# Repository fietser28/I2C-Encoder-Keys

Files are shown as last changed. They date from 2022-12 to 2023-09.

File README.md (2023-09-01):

<!--
  SPDX-FileCopyrightText: 2023 Jan Nieuwstad <jan.sources@nieuwstad.net>
  SPDX-License-Identifier: CERN-OHL-W-2.0
-->



# Introduction

This is simple design to connect a rotary encoder with pushbutton and 4 switches to an MCU using I2C. The design uses the common MCP23008 chip. The BOM is kept simple with as many common parts as possible. The encoder and switches have a small RC network in place for basic debouncing (you still need to handle this also in software).

The board breaks out 3V3 power input, GND, SCL, SDA, Interrupt and !Reset.

The board provides pull up resistors for SCL, SDA and the !RESET pin. For each of them there also is a jumper to disable them.

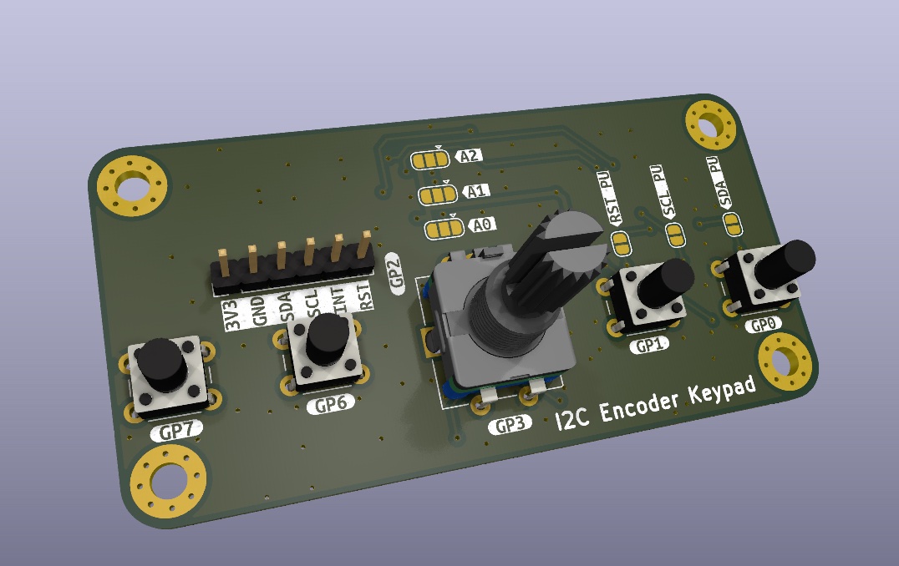
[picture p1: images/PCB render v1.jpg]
alt Raytraced front of PCB with components


NOTE: The rendering above has an encoder with round shaft, the knob is for an encoder with a D shaped shaft.

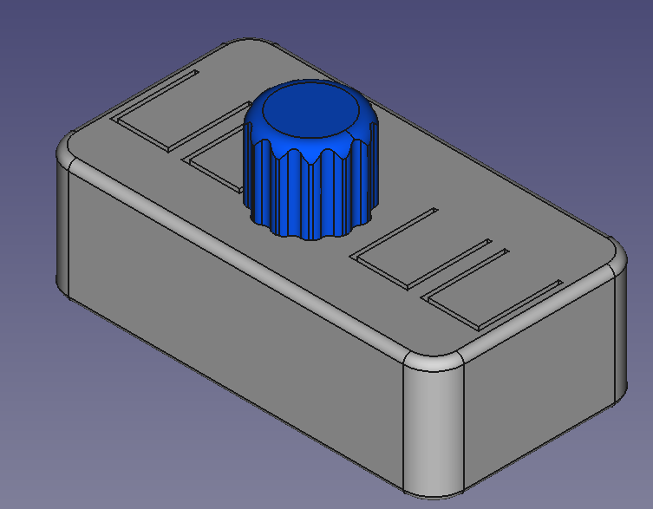
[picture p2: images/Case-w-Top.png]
alt Raytraced case with knob


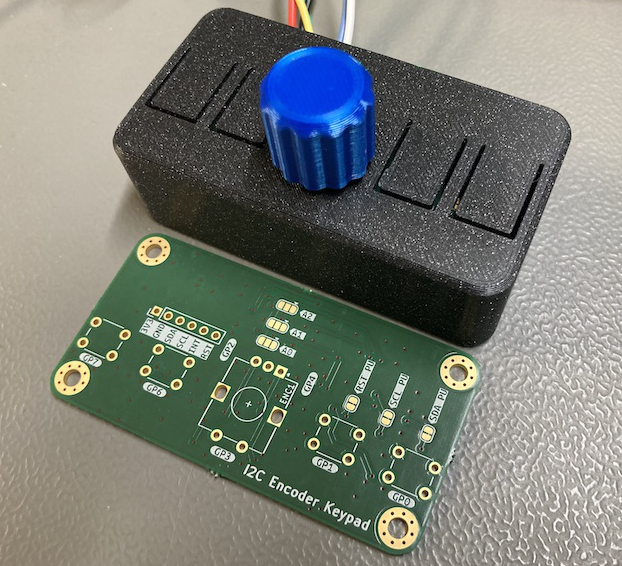
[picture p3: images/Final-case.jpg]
alt Photo of assembled case with knob


This board can be daisy chained. You just have to make sure each board uses a different addres by changing the jumpers A0,A1 and/or A2. Make sure you use the opendrain configuration of the interrupt pin if you want to use interrupts in this case.

# Files

 - The directory I2C-Encoder-Keys contains the KiCad (6) design files.
 - The BOM directory contains an bill of material generated by KiCad
 - 3D contains FreeCad design and 3D printable files (STL) for a case.
 - The root directory contains PDF of the schematic and PCB design.

# License 

This hardware design is under the [CERN Open Hardware Licence Version 2 - Weakly Reciprocal](LICENSES/CERN-OHL-W-4.0.txt)
Illustrations are under the [CERN Open Hardware Licence Version 2 - Weakly Reciprocal](LICENSES/CC-BY-SA-4.0.txt)

This project contains 3D models from others:
- [JST PH connector](https://grabcad.com/library/jst-ph-2-0mm-connector-pack-through-hole-smt-ds1066-1) from Sig Elso <https://grabcad.com/sig.elso-1>
- [Rotary encoder](https://grabcad.com/library/ec11-rotary-encoder-with-switch-1) from Anthony Berkow <https://grabcad.com/anthony.berkow-1>

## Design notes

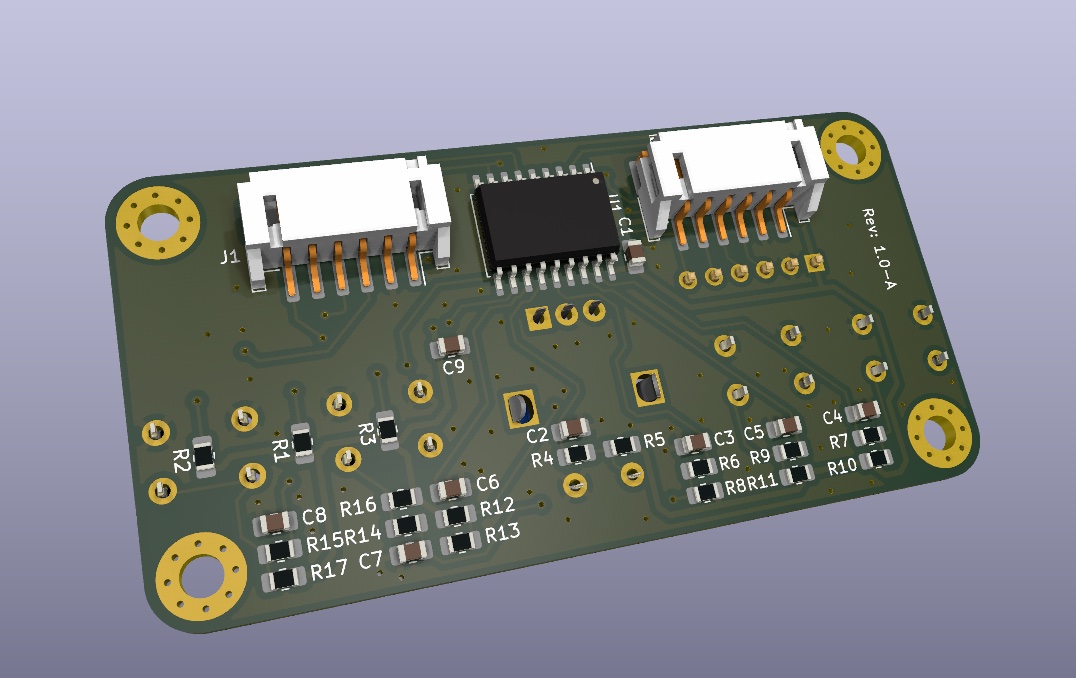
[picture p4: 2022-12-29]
images/PCB render v1 back.jpg

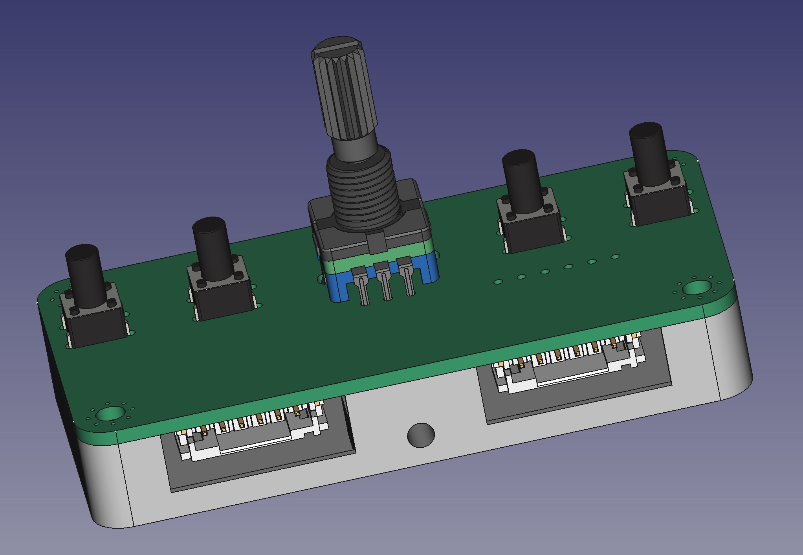
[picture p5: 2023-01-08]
images/Case-bottom-back.jpg

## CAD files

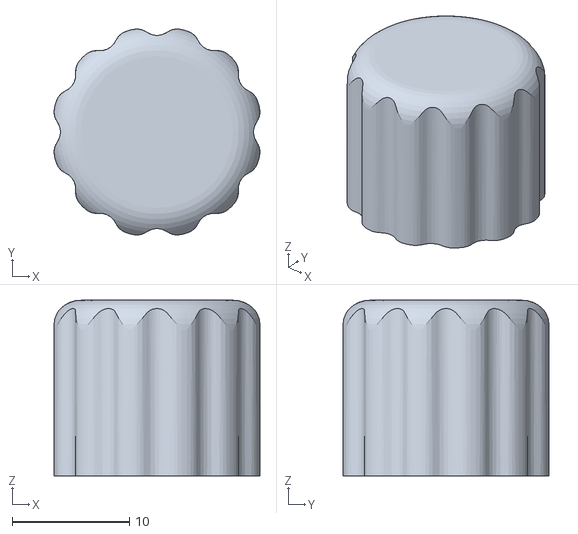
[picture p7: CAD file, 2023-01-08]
3D/I2C-Encoder-Keys-Knob.stl
17.6 x 17.6 x 15.0

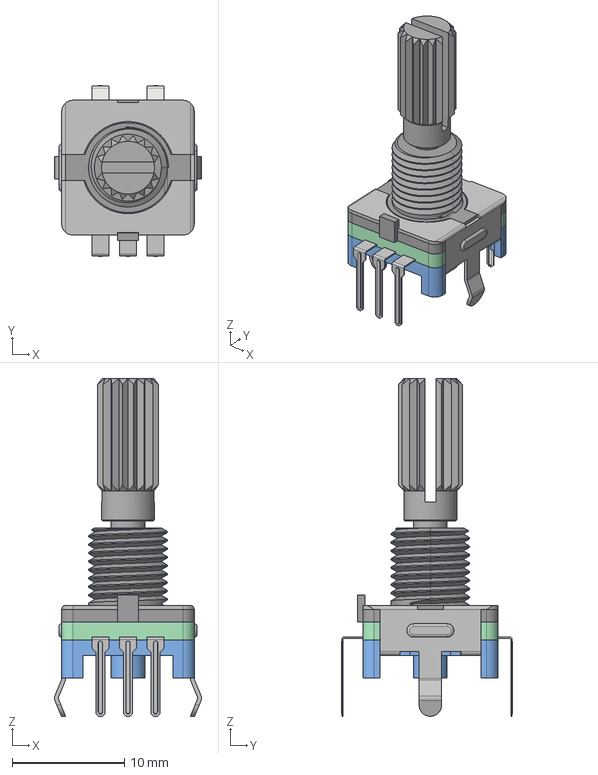
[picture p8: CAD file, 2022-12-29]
I2C-Encoder-Keys/models/ec11-rotary-encoder-with-switch-1/EC11_Rotary_Encoder_Switched.step
13.1 x 15.3 x 30.1 mm

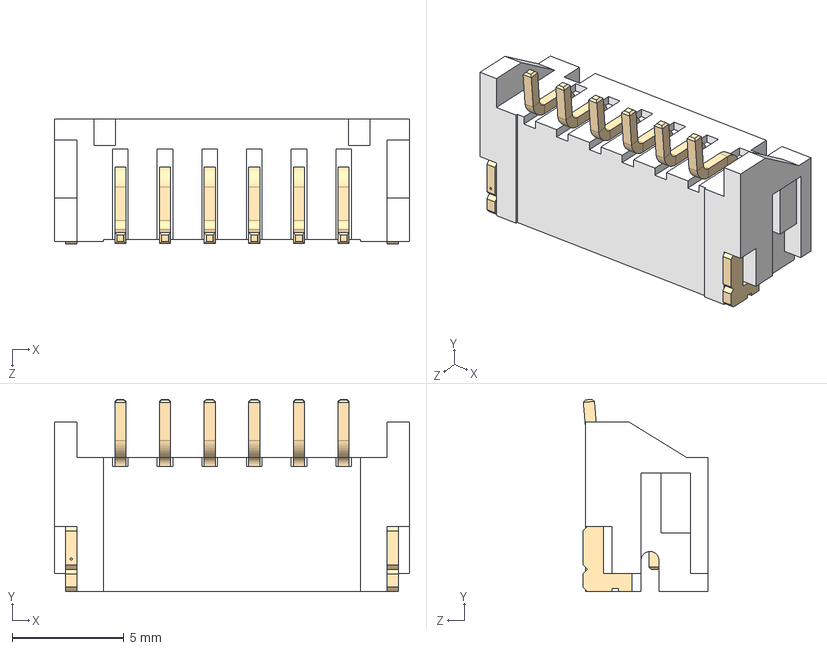
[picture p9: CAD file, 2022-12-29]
I2C-Encoder-Keys/models/JST-S6B-PH-SM4/JST-S6B-PH-SM4-TB.STEP
15.9 x 8.61 x 5.61 mm

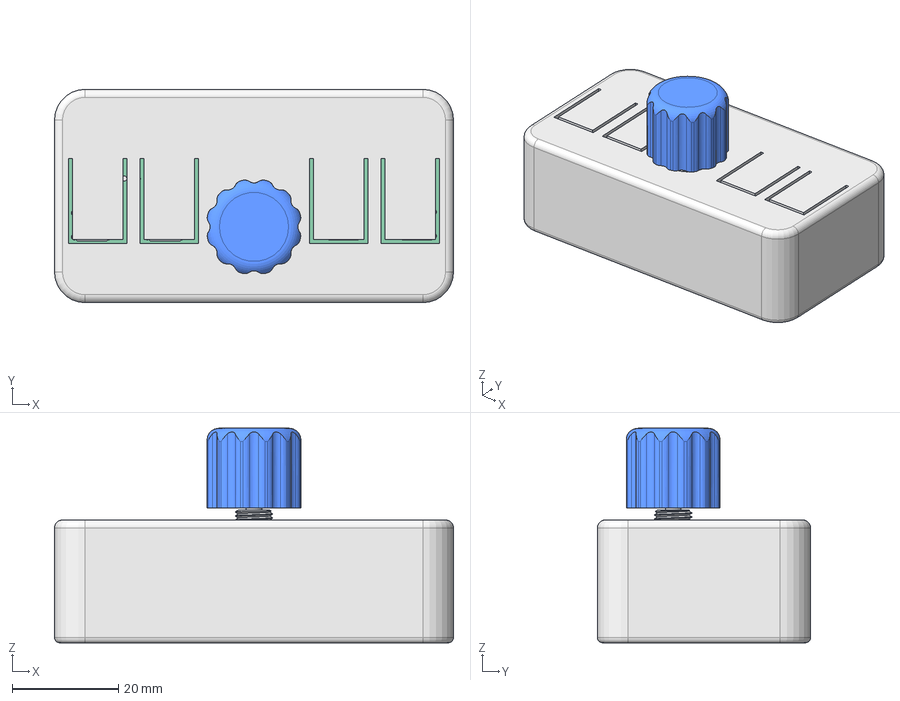
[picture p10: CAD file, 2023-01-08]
3D/I2C-Encoder-Keys-Case.FCStd
75.0 x 40.1 x 40.4 mm
Pcb_cce4
EC11_Rotary_Encoder_Switched
EC11_Rotary_Encoder_Switched001
EC11_Rotary_Encoder_Switched002
EC11_Rotary_Encoder_Switched003
EC11_Rotary_Encoder_Switched004
EC11_Rotary_Encoder_Switched005
EC11_Rotary_Encoder_Switched006
EC11_Rotary_Encoder_Switched007
EC11_Rotary_Encoder_Switched008
EC11_Rotary_Encoder_Switched009
SW1_SW_PUSH_6mm_h9.5mm_fd6cde793684 x 4
R14_R_0805_2012Metric_56405198e740 x 17
C8_C_0805_2012Metric_ab4888782af2 x 9
U1_SOIC_18W_75x116mm_P127mm_2b728b92b7df

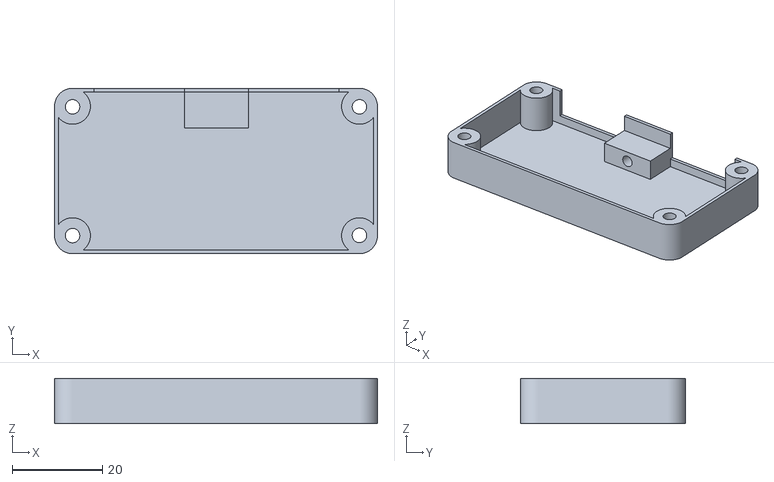
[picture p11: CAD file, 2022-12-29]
3D/I2C-Encoder-Keys-Case-Case Bottom.stl
71.5 x 36.6 x 10.0

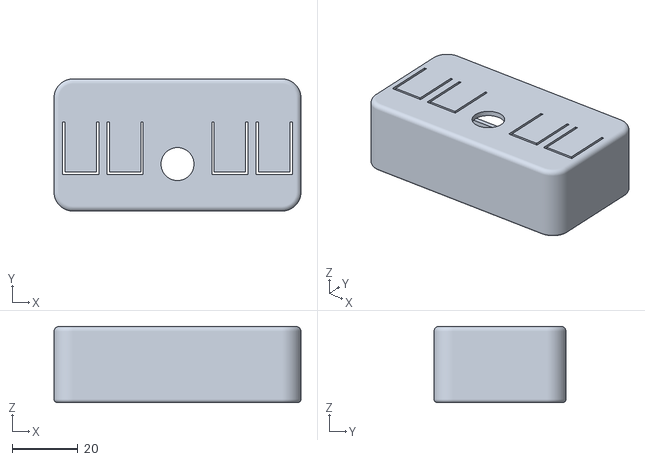
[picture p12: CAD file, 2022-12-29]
3D/I2C-Encoder-Keys-Case-Case Top.stl
75.0 x 40.1 x 23.1

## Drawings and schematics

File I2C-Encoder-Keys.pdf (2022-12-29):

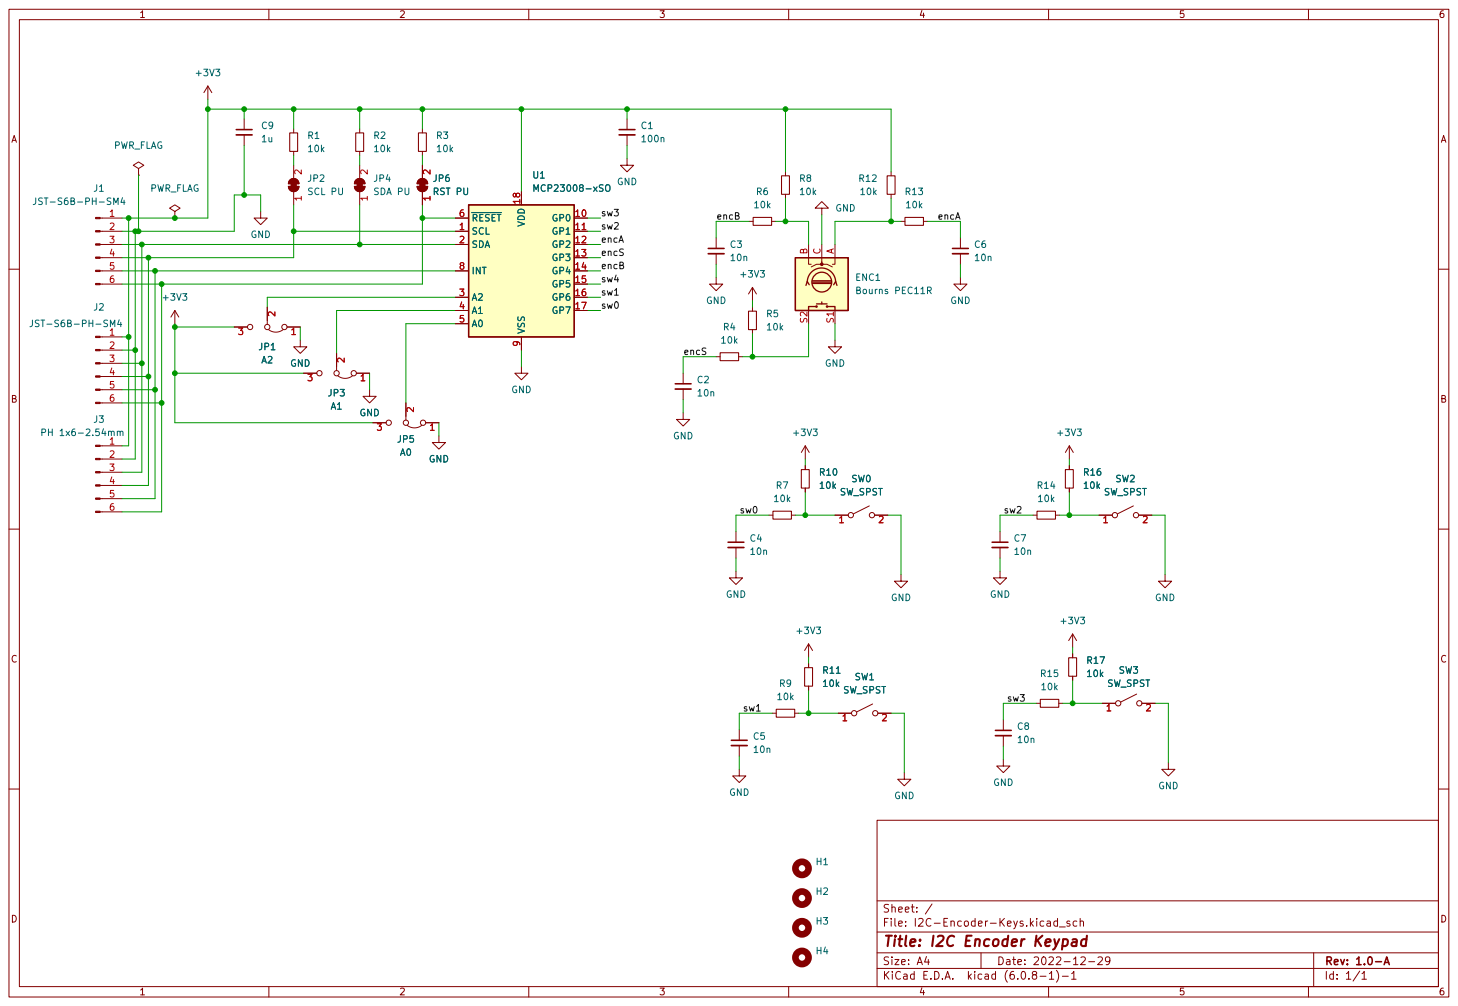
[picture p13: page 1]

File: I2C-Encoder-Keys.kicad_sch Sheet: / C4

Id: 1/1 Title: I2C Encoder Keypad

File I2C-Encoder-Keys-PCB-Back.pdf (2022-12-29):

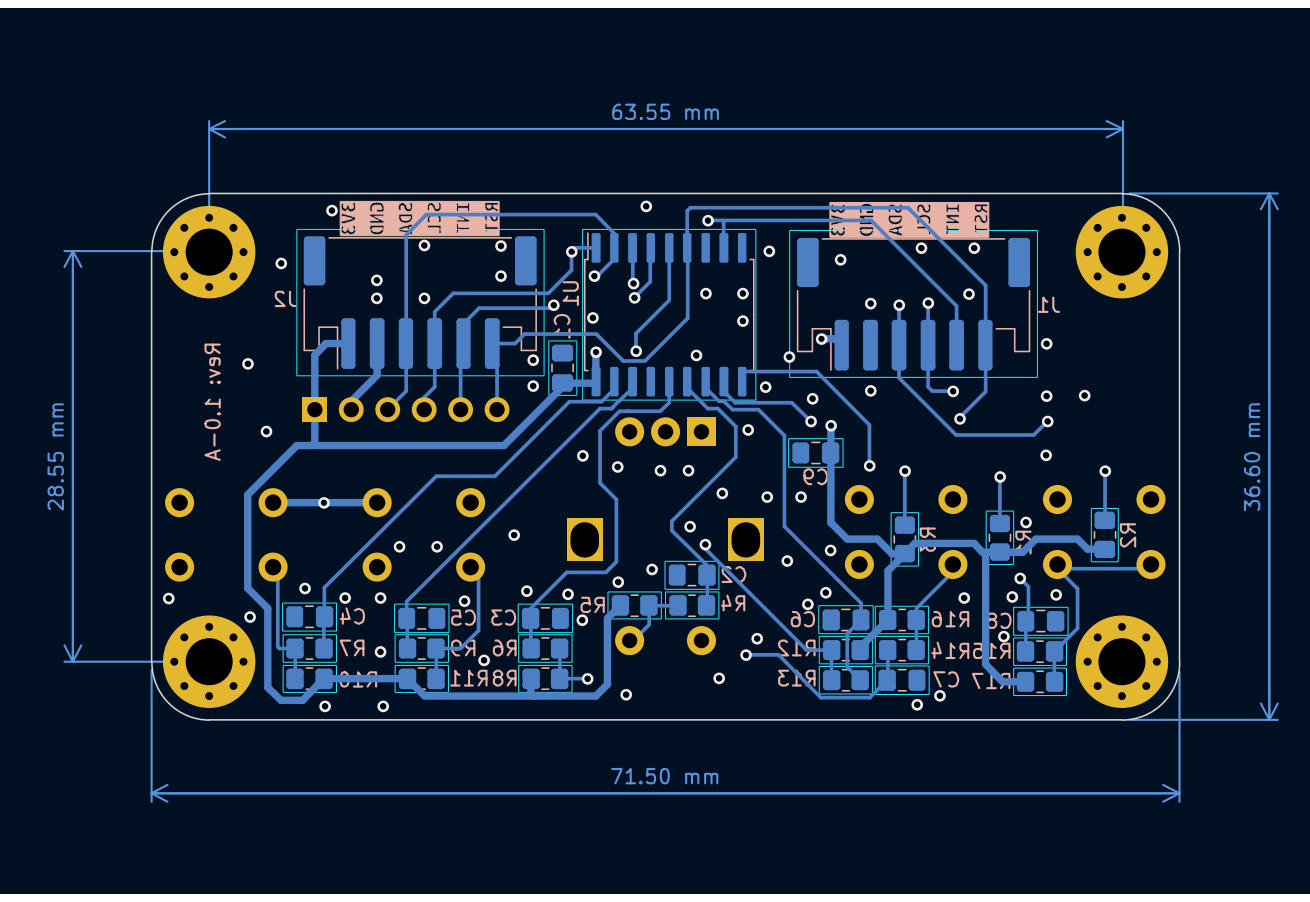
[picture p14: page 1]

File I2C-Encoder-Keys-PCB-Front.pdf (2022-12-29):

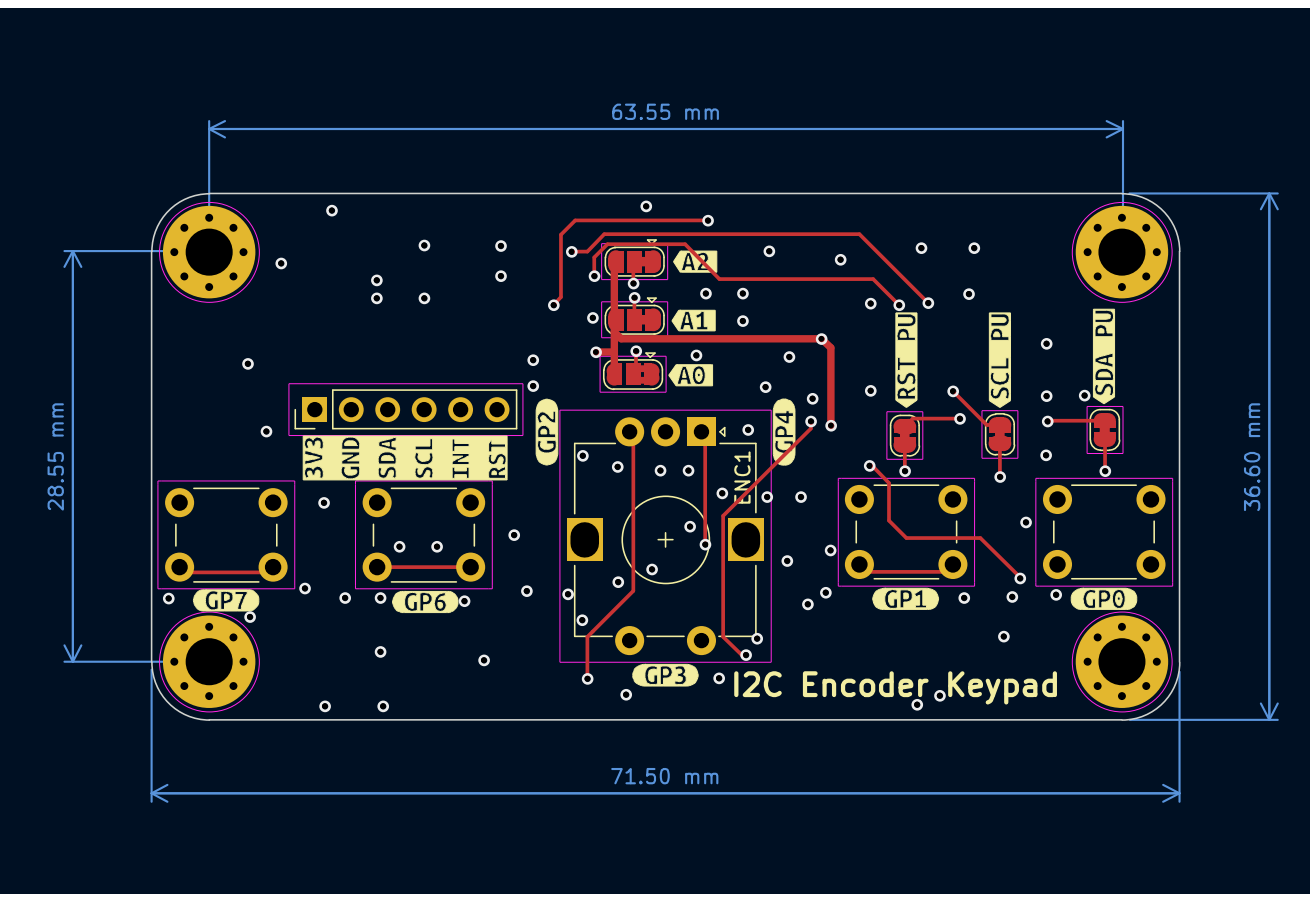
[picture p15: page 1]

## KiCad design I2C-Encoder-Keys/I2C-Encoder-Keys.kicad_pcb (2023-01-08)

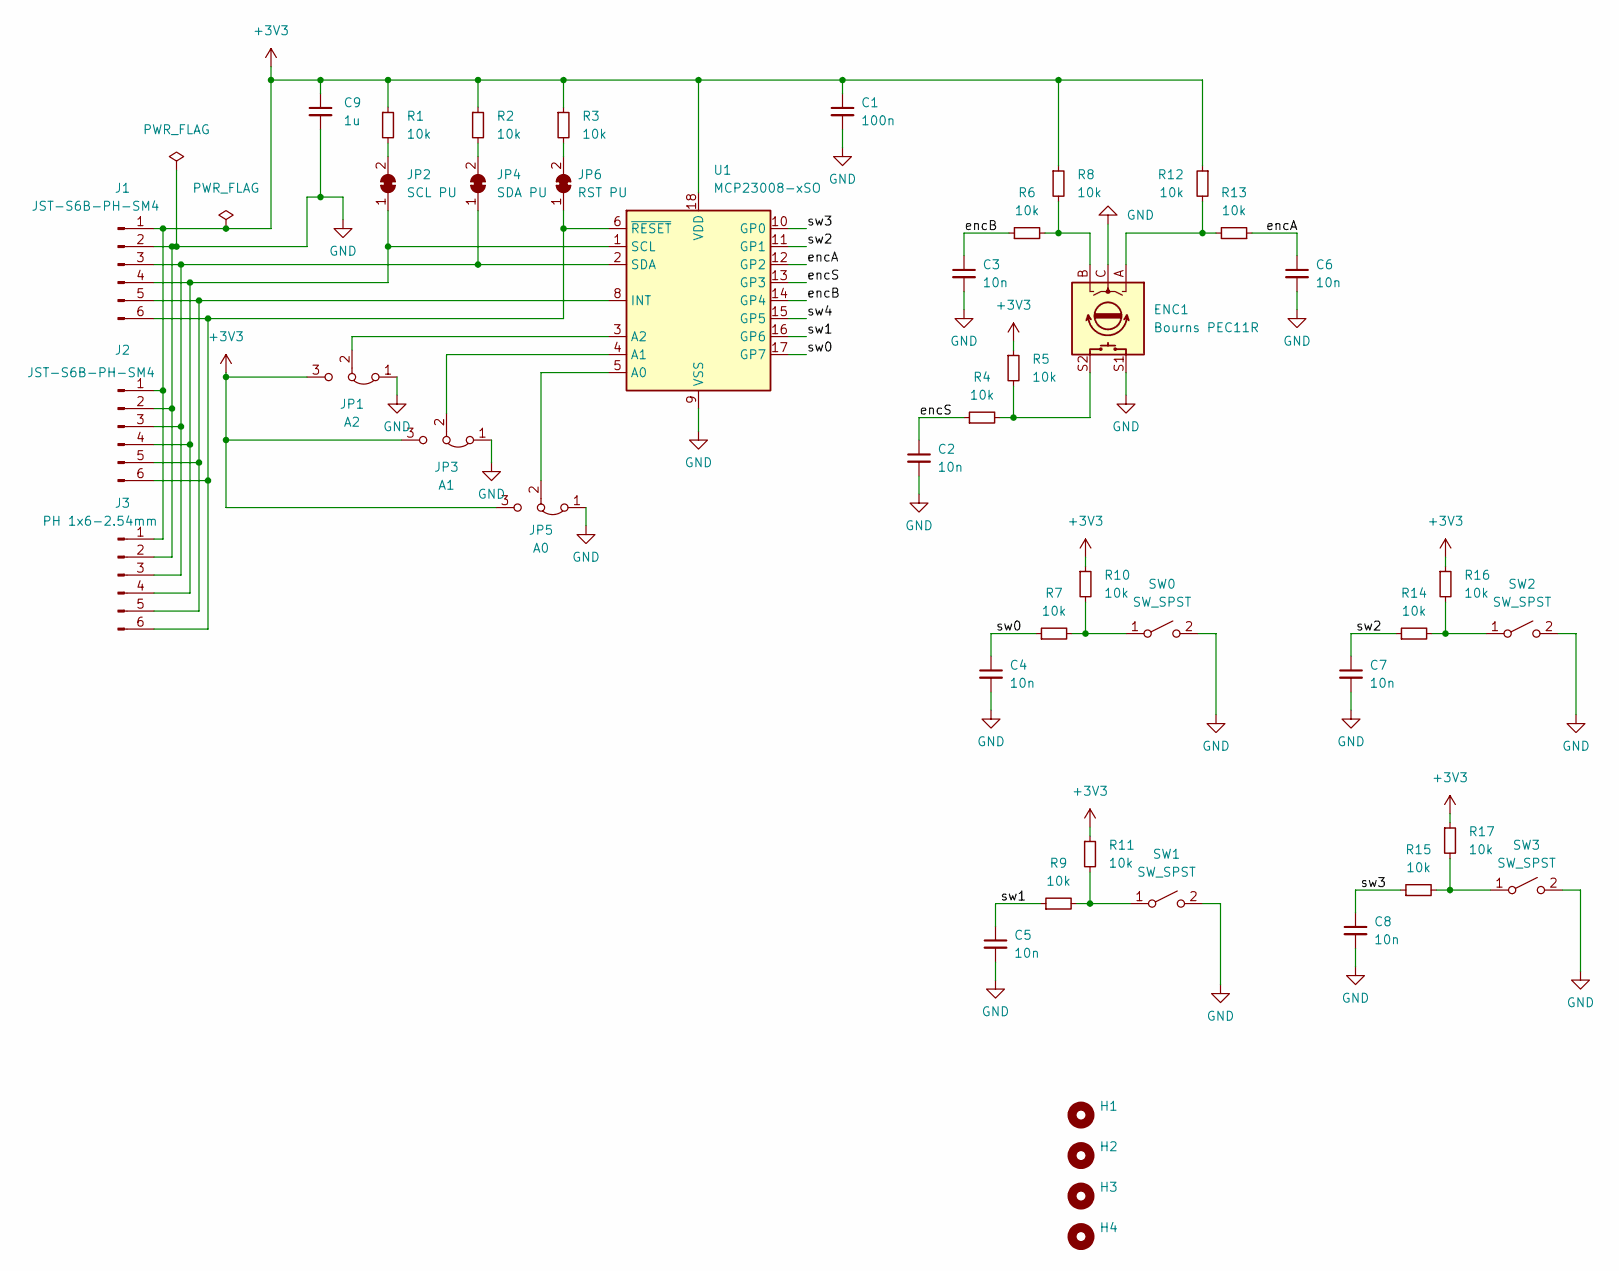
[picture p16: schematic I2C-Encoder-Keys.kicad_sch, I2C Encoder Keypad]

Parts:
C1: 100n; C_0805_2012Metric_Pad1.18x1.45mm_HandSolder; LCSC Part # C49678
C2, C3, C4, C5, C6, C7, C8: 10n; C_0805_2012Metric_Pad1.18x1.45mm_HandSolder; LCSC Part # C1710
C9: 1u; C_0805_2012Metric_Pad1.18x1.45mm_HandSolder; LCSC Part # C28323
ENC1: Bourns PEC11R; RotaryEncoder_Alps_EC12E-Switch_Vertical_H20mm
H1, H2, H3, H4: MountingHole; MountingHole_3.2mm_M3_Pad_Via
J1, J2: JST-S6B-PH-SM4; JST_PH_S6B-PH-SM4-TB_1x06-1MP_P2.00mm_Horizontal; LCSC Part # C265405
J3: PH 1x6-2.54mm; PinHeader_1x06_P2.54mm_Vertical
JP1: A2; SolderJumper-3_P1.3mm_Bridged12_RoundedPad1.0x1.5mm
JP2: SCL PU; SolderJumper-2_P1.3mm_Bridged_RoundedPad1.0x1.5mm
JP3: A1; SolderJumper-3_P1.3mm_Bridged12_RoundedPad1.0x1.5mm
JP4: SDA PU; SolderJumper-2_P1.3mm_Bridged_RoundedPad1.0x1.5mm
JP5: A0; SolderJumper-3_P1.3mm_Bridged2Bar12_RoundedPad1.0x1.5mm
JP6: RST PU; SolderJumper-2_P1.3mm_Bridged_RoundedPad1.0x1.5mm
R1, R2, R3, R4, R5, R6, R7, R8, R9, R10, R11, R12, R13, R14, R15, R16, R17: 10k; R_0805_2012Metric_Pad1.20x1.40mm_HandSolder; LCSC Part # C17414
SW0, SW1, SW2, SW3: SW_SPST; SW_PUSH_6mm_H9.5mm
U1: MCP23008-xSO; SOIC-18W_7.5x11.6mm_P1.27mm; LCSC Part # C92253

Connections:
+3V3: C1.1, C9.1, J1.1, J2.1, J3.1, JP1.3 (B), JP3.3 (B), JP5.3 (B), R1.1, R2.1, R3.1, R5.1, R8.1, R10.1, R11.1, R12.1, R16.1, R17.1, U1.18 (VDD)
/encA: C6.1, R13.1, U1.12 (GP2)
/encB: C3.1, R6.1, U1.14 (GP4)
/encS: C2.1, R4.1, U1.13 (GP3)
/sw0: C4.1, R7.1, U1.17 (GP7)
/sw1: C5.1, R9.1, U1.16 (GP6)
/sw2: C7.1, R14.1, U1.11 (GP1)
/sw3: C8.1, R15.1, U1.10 (GP0)
/sw4: U1.15 (GP5)
GND: C1.2, C2.2, C3.2, C4.2, C5.2, C6.2, C7.2, C8.2, C9.2, ENC1.C, ENC1.S1, J1.2, J2.2, J3.2, JP1.1 (A), JP3.1 (A), JP5.1 (A), SW0.2 (B), SW1.2 (B), SW2.2 (B), SW3.2 (B), U1.9 (VSS)
unnamed: ENC1.A, R12.2, R13.2
unnamed: ENC1.B, R6.2, R8.2
unnamed: ENC1.S2, R4.2, R5.2
unnamed: J1.3, J2.3, J3.3, JP4.1 (A), U1.2 (SDA)
unnamed: J1.4, J2.4, J3.4, JP2.1 (A), U1.1 (SCL)
unnamed: J1.5, J2.5, J3.5, U1.8 (INT)
unnamed: J1.6, J2.6, J3.6, JP6.1 (A), U1.6 (~RESET)
unnamed: JP1.2 (C), U1.3 (A2)
unnamed: JP2.2 (B), R1.2
unnamed: JP3.2 (C), U1.4 (A1)
unnamed: JP4.2 (B), R2.2
unnamed: JP5.2 (C), U1.5 (A0)
unnamed: JP6.2 (B), R3.2
unnamed: R7.2, R10.2, SW0.1 (A)
unnamed: R9.2, R11.2, SW1.1 (A)
unnamed: R14.2, R16.2, SW2.1 (A)
unnamed: R15.2, R17.2, SW3.1 (A)

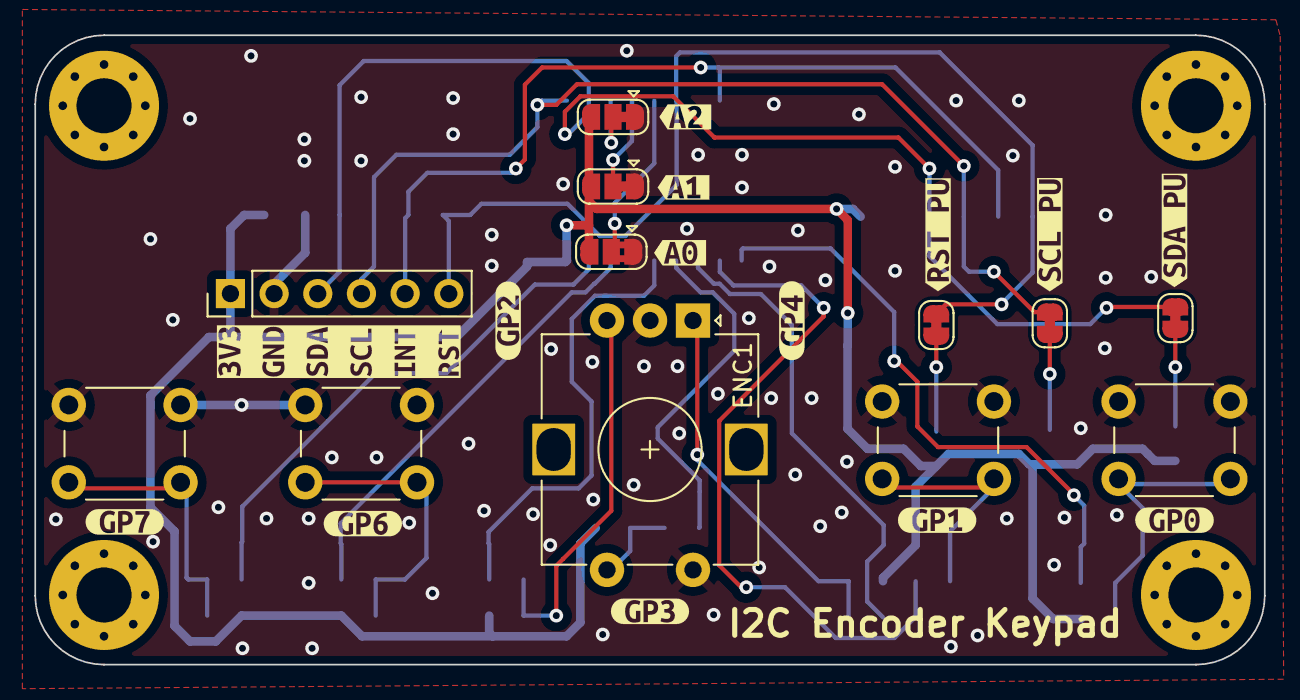
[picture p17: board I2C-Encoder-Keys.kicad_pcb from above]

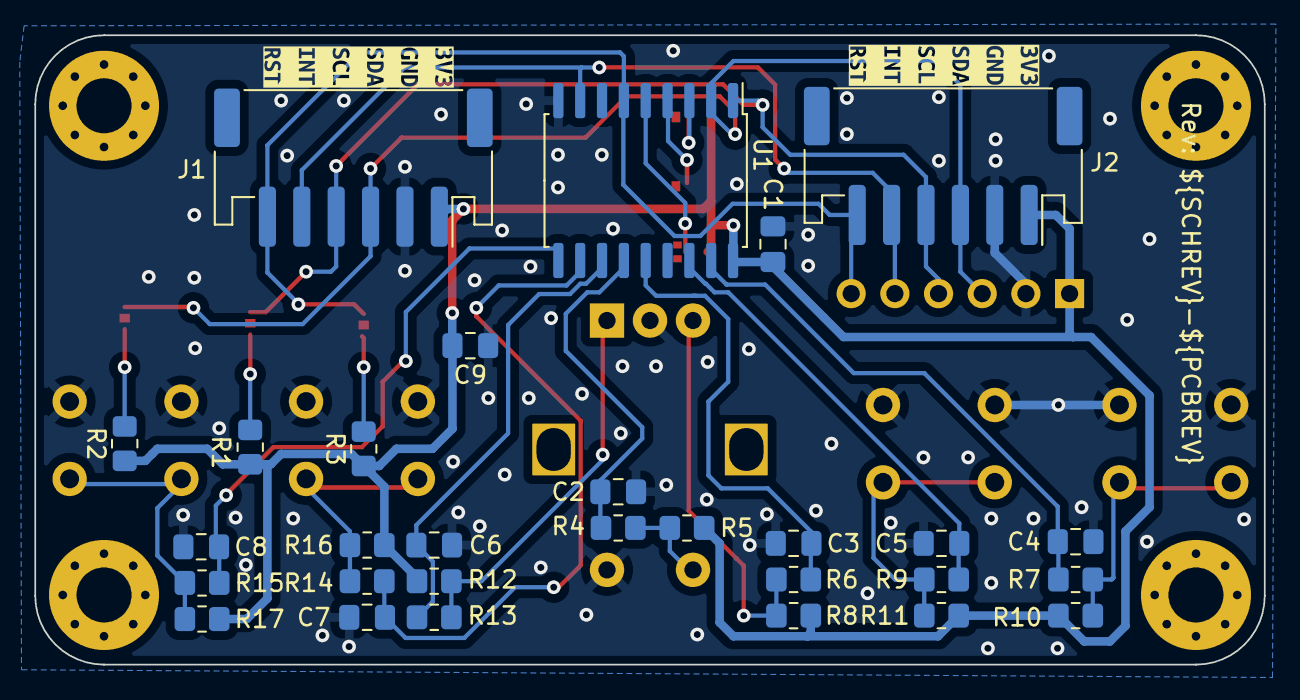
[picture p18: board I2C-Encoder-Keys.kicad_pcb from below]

Board: 2 copper layers, 71.5 x 36.6 mm, 61 parts (31 on the bottom side), 26 nets.

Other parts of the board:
kibuzzard-63ABAB39: G***; kibuzzard-63ABAB39
kibuzzard-63ABAB54: G***; kibuzzard-63ABAB54
kibuzzard-63ABAB66: G***; kibuzzard-63ABAB66
kibuzzard-63ABAFD8: G***; kibuzzard-63ABAFD8
kibuzzard-63ABB001: G***; kibuzzard-63ABB001
kibuzzard-63ABB1F4: G***; kibuzzard-63ABB1F4
kibuzzard-63ABB06A: G***; kibuzzard-63ABB06A
kibuzzard-63ABB13E: G***; kibuzzard-63ABB13E
kibuzzard-63ABB15D: G***; kibuzzard-63ABB15D
kibuzzard-63ABB22D: G***; kibuzzard-63ABB22D
kibuzzard-63ABB036: G***; kibuzzard-63ABB036
kibuzzard-63ABB131: G***; kibuzzard-63ABB131
kibuzzard-63ABB252: G***; kibuzzard-63ABB252
kibuzzard-63ADADA8: G***; kibuzzard-63ADADA8
kibuzzard-63ADBF96, kibuzzard-63ADBF96#2: G***; kibuzzard-63ADBF96

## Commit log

2022-12-29 initial commit - v1.0-A
    [EC11_Rotary_Encoder_Switched.step, I2C-Encoder-Keys-Case-Case Bottom.stl, I2C-Encoder-Keys-Case-Case Top.stl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]
2023-01-08 Added encoder knob
    [I2C-Encoder-Keys-Case.FCStd, I2C-Encoder-Keys-Knob.stl, I2C-Encoder-Keys.kicad_pcb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]
